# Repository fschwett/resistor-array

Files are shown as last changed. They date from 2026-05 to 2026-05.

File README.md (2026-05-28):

# Resistor array

## Idea:

I wanted to have a resistor array for test purposes. After seeing extremely expensive ones online I decided to create my own. My plan was to order it along with other PCBs, but that didn't end up happening.

## Concept:

An array of resistors which can be added to or removed from the total resistance. I wanted to order five PCBs to be able to play around with values more freely and be able to for example coordinate two resistances. I went with the classic 1, 2, 3, 4 design most of these arrays use. This means I have 1 Ω, 10 Ω, 100 Ω, 1 kΩ, 10 kΩ, 100 kΩ and 1 MΩ, then 2 Ω, 20 Ω and so on. This let's me get any nominal value from 0 Ω to 11.111.110 Ω.

## Implementation:

I had some SMD SPDT slide switches laying around. I chose SMD, because it would give the PCB a clean back. THT could've made contact with other parts and could've ended up shorting the whole thing. For some of the values I had to comine resistors, because I didn't have the right ones or they simple weren't part of the e series. I also used SMD resistors. This had the disadvantage of a low power rating though. Mine are .25 W 1% resistors. Unfortunately I don't know the temperature coefficient of these resistors, but I assume it's between 100 ppm and 200 ppm.

That's the actual design:



The traces are as large as possible to reduce resistance.

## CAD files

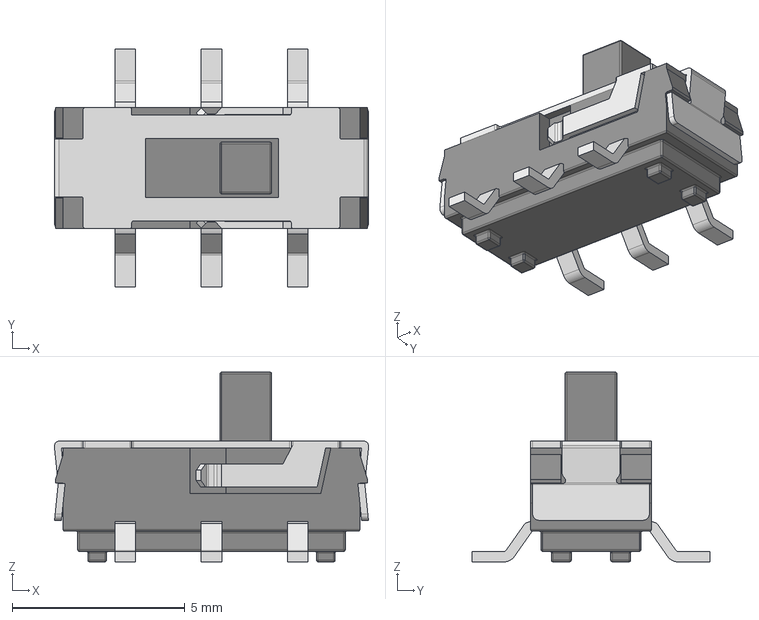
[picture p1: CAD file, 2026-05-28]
KiCad/components/smd-spdt/SLW-913535-2A-SMT.stp
9.10 x 6.90 x 5.50 mm

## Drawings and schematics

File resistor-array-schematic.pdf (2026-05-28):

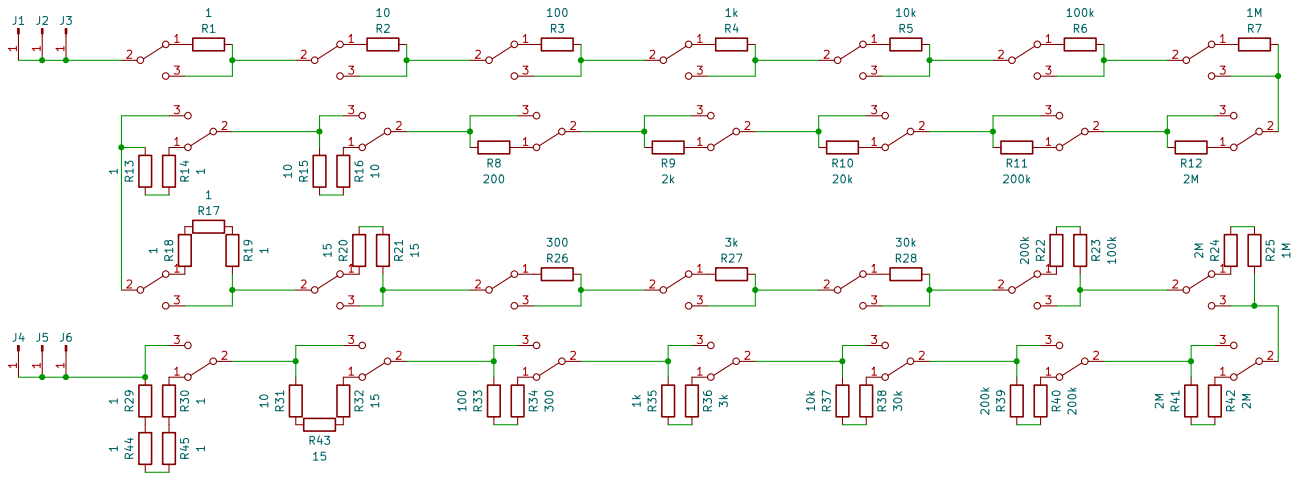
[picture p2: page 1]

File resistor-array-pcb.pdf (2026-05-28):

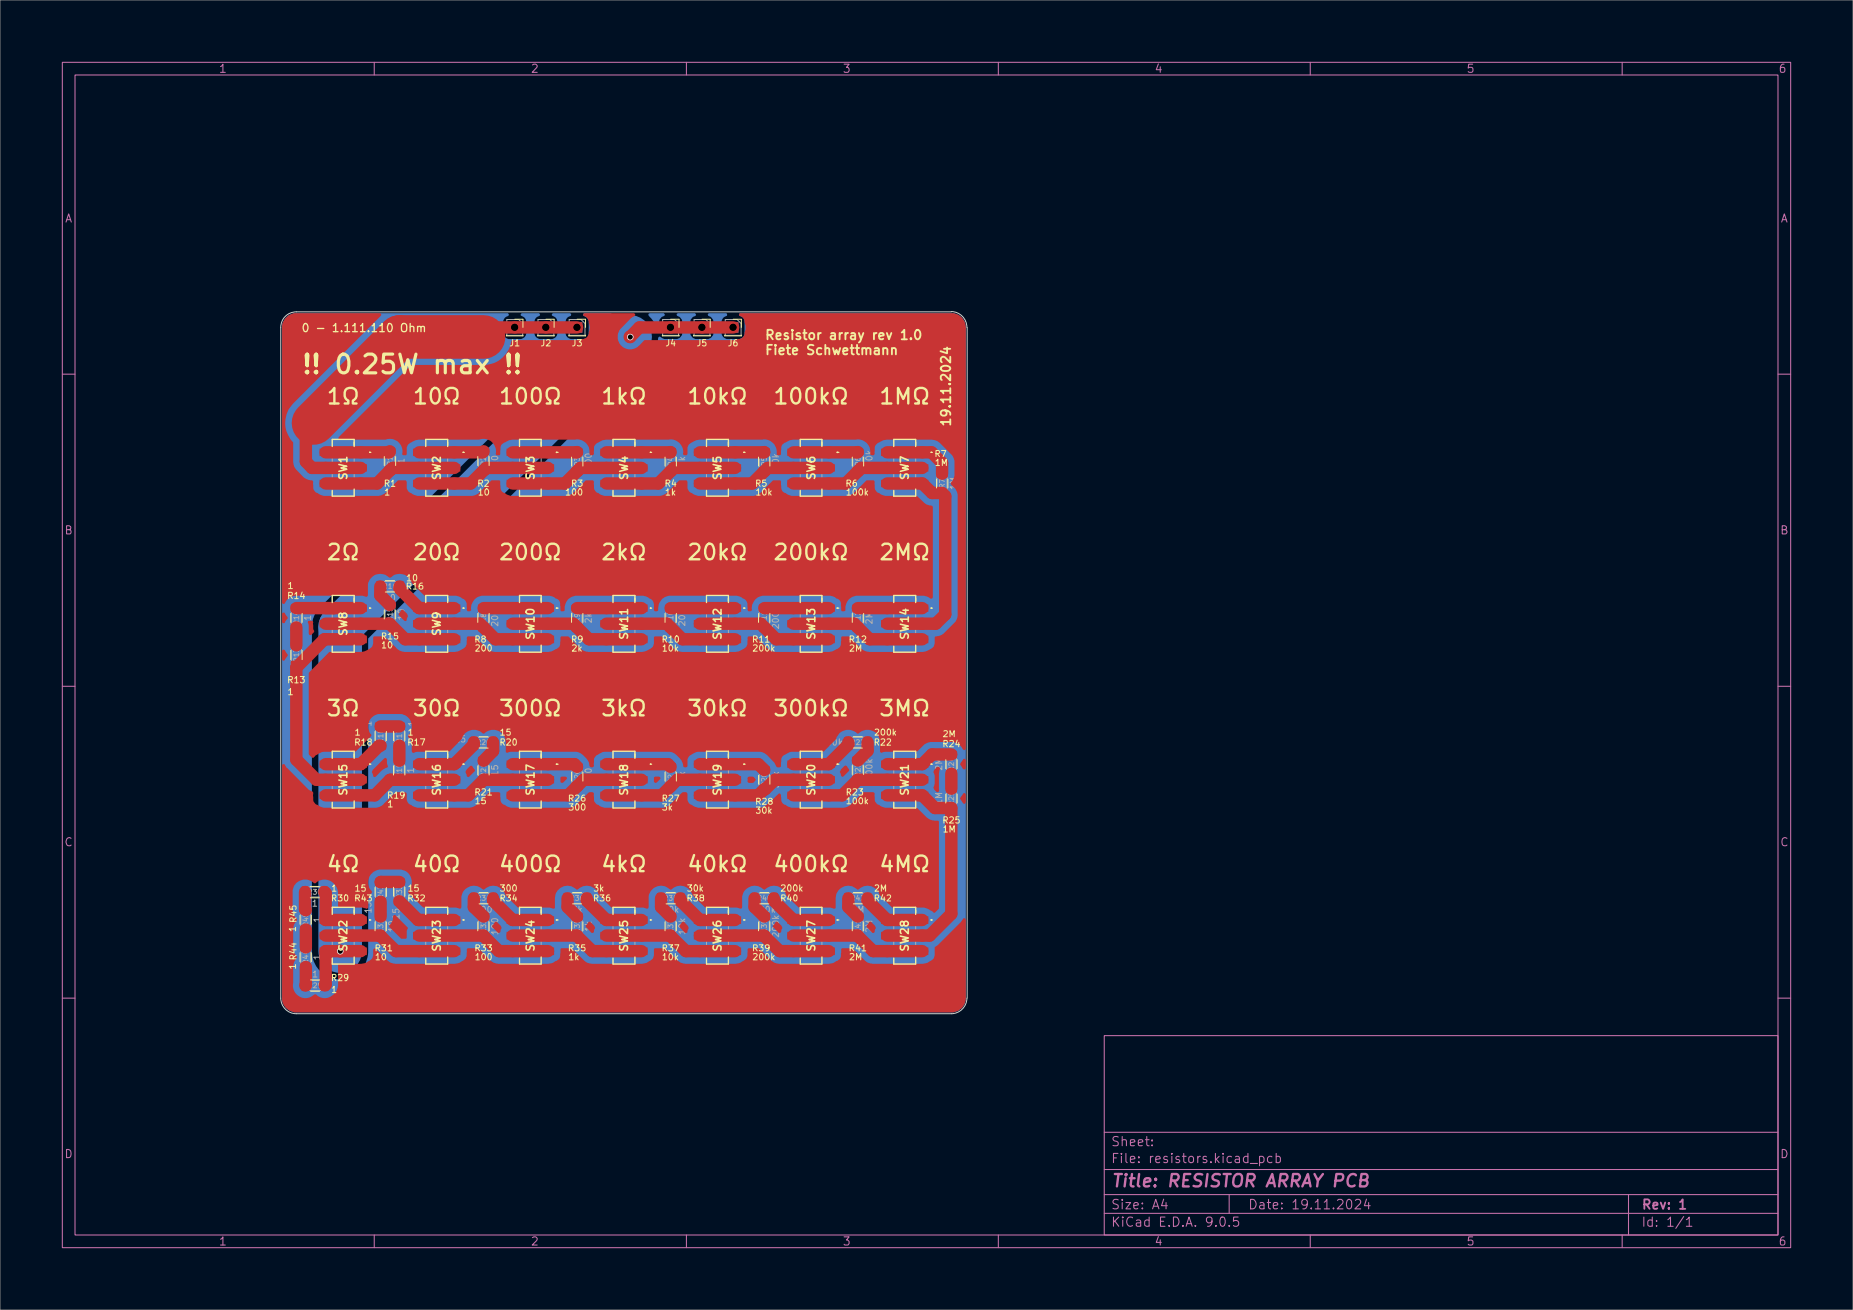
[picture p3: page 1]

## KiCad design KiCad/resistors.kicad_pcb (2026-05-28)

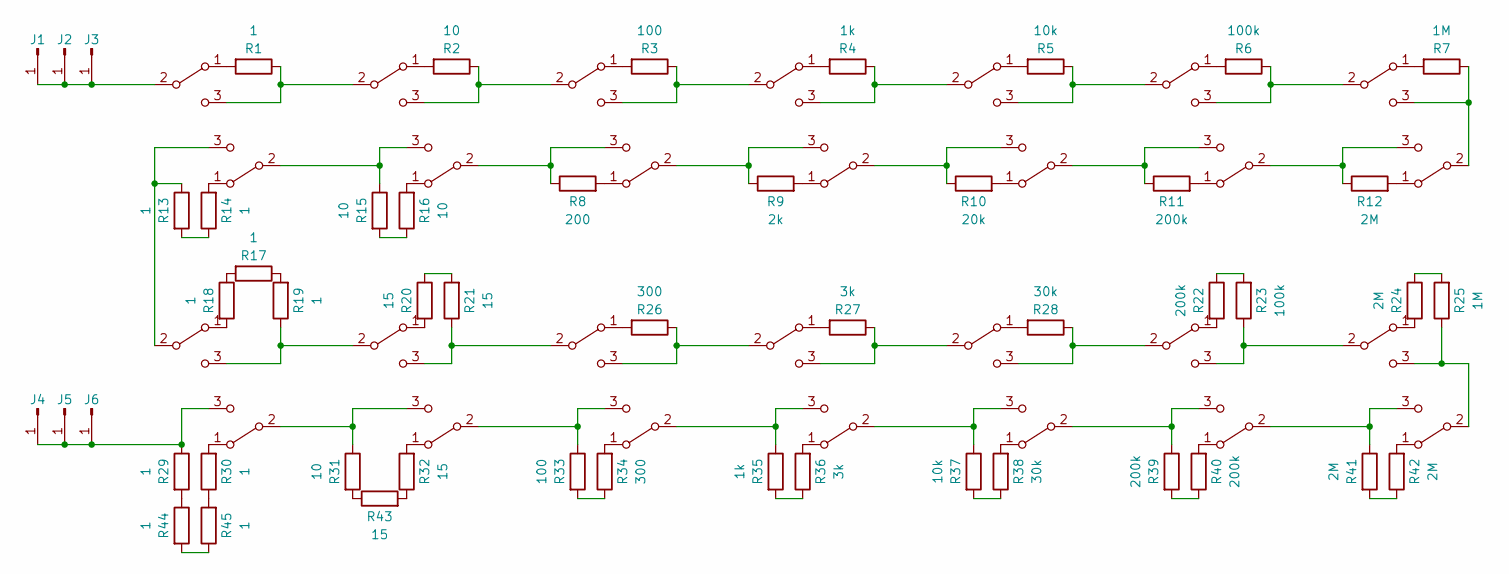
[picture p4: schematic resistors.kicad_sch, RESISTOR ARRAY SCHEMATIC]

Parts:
J1, J2, J3, J4, J5, J6: Conn_01x01_Pin; PinSocket_1x01_P2.54mm_Vertical
R1, R13, R14, R17, R18, R19, R29, R30, R44, R45: 1; R_1206_3216Metric_Pad1.30x1.75mm_HandSolder
R2, R15, R16, R31: 10; R_1206_3216Metric_Pad1.30x1.75mm_HandSolder
R3, R33: 100; R_1206_3216Metric_Pad1.30x1.75mm_HandSolder
R4, R35: 1k; R_1206_3216Metric_Pad1.30x1.75mm_HandSolder
R5, R37: 10k; R_1206_3216Metric_Pad1.30x1.75mm_HandSolder
R6, R23: 100k; R_1206_3216Metric_Pad1.30x1.75mm_HandSolder
R7, R25: 1M; R_1206_3216Metric_Pad1.30x1.75mm_HandSolder
R8: 200; R_1206_3216Metric_Pad1.30x1.75mm_HandSolder
R9: 2k; R_1206_3216Metric_Pad1.30x1.75mm_HandSolder
R10: 20k; R_1206_3216Metric_Pad1.30x1.75mm_HandSolder
R11, R22, R39, R40: 200k; R_1206_3216Metric_Pad1.30x1.75mm_HandSolder
R12, R24, R41, R42: 2M; R_1206_3216Metric_Pad1.30x1.75mm_HandSolder
R20, R21, R32, R43: 15; R_1206_3216Metric_Pad1.30x1.75mm_HandSolder
R26, R34: 300; R_1206_3216Metric_Pad1.30x1.75mm_HandSolder
R27, R36: 3k; R_1206_3216Metric_Pad1.30x1.75mm_HandSolder
R28, R38: 30k; R_1206_3216Metric_Pad1.30x1.75mm_HandSolder
SW1, SW2, SW3, SW4, SW5, SW6, SW7, SW8, SW9, SW10, SW11, SW12, SW13, SW14, SW15, SW16, SW17, SW18, SW19, SW20, SW21, SW22, SW23, SW24, SW25, SW26, SW27, SW28: SW_SPDT; SLW9135352ASMT

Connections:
unnamed: J1.1, J2.1, J3.1, SW1.2 (B)
unnamed: J4.1, J5.1, J6.1, R29.1, SW22.3 (C)
unnamed: R13.2, R14.1
unnamed: R15.2, R16.1
unnamed: R17.1, R19.2
unnamed: R17.2, R18.1
unnamed: R20.1, R21.2
unnamed: R22.1, R23.2
unnamed: R24.1, R25.2
unnamed: R29.2, R44.1
unnamed: R30.1, R45.2
unnamed: R31.2, R43.1
unnamed: R32.1, R43.2
unnamed: R33.2, R34.1
unnamed: R35.2, R36.1
unnamed: R37.2, R38.1
unnamed: R39.2, R40.1
unnamed: R41.2, R42.1
unnamed: R44.2, R45.1
unnamed: R1.2, SW1.1 (A)
unnamed: R1.1, SW1.3 (C), SW2.2 (B)
unnamed: R2.2, SW2.1 (A)
unnamed: R2.1, SW2.3 (C), SW3.2 (B)
unnamed: R3.2, SW3.1 (A)
unnamed: R3.1, SW3.3 (C), SW4.2 (B)
unnamed: R4.2, SW4.1 (A)
unnamed: R4.1, SW4.3 (C), SW5.2 (B)
unnamed: R5.2, SW5.1 (A)
unnamed: R5.1, SW5.3 (C), SW6.2 (B)
unnamed: R6.2, SW6.1 (A)
unnamed: R6.1, SW6.3 (C), SW7.2 (B)
unnamed: R7.2, SW7.1 (A)
unnamed: R14.2, SW8.1 (A)
unnamed: R15.1, SW8.2 (B), SW9.3 (C)
unnamed: R16.2, SW9.1 (A)
unnamed: R8.2, SW10.1 (A)
unnamed: R9.1, SW10.2 (B), SW11.3 (C)
unnamed: R8.1, SW9.2 (B), SW10.3 (C)
unnamed: R9.2, SW11.1 (A)
unnamed: R10.1, SW11.2 (B), SW12.3 (C)
unnamed: R10.2, SW12.1 (A)
unnamed: R11.1, SW12.2 (B), SW13.3 (C)
unnamed: R11.2, SW13.1 (A)
unnamed: R12.1, SW13.2 (B), SW14.3 (C)
unnamed: R12.2, SW14.1 (A)
unnamed: R7.1, SW7.3 (C), SW14.2 (B)
unnamed: R18.2, SW15.1 (A)
unnamed: R13.1, SW8.3 (C), SW15.2 (B)
unnamed: R19.1, SW15.3 (C), SW16.2 (B)
unnamed: R20.2, SW16.1 (A)
unnamed: R21.1, SW16.3 (C), SW17.2 (B)
unnamed: R26.2, SW17.1 (A)
unnamed: R26.1, SW17.3 (C), SW18.2 (B)
unnamed: R27.2, SW18.1 (A)
unnamed: R27.1, SW18.3 (C), SW19.2 (B)
unnamed: R28.2, SW19.1 (A)
unnamed: R28.1, SW19.3 (C), SW20.2 (B)
unnamed: R22.2, SW20.1 (A)
unnamed: R23.1, SW20.3 (C), SW21.2 (B)
unnamed: R24.2, SW21.1 (A)
unnamed: R25.1, SW21.3 (C), SW28.2 (B)
unnamed: R30.2, SW22.1 (A)
unnamed: R31.1, SW22.2 (B), SW23.3 (C)
unnamed: R32.2, SW23.1 (A)
unnamed: R33.1, SW23.2 (B), SW24.3 (C)
unnamed: R34.2, SW24.1 (A)
unnamed: R35.1, SW24.2 (B), SW25.3 (C)
unnamed: R36.2, SW25.1 (A)
unnamed: R37.1, SW25.2 (B), SW26.3 (C)
unnamed: R38.2, SW26.1 (A)
unnamed: R39.1, SW26.2 (B), SW27.3 (C)
unnamed: R40.2, SW27.1 (A)
unnamed: R41.1, SW27.2 (B), SW28.3 (C)
unnamed: R42.2, SW28.1 (A)

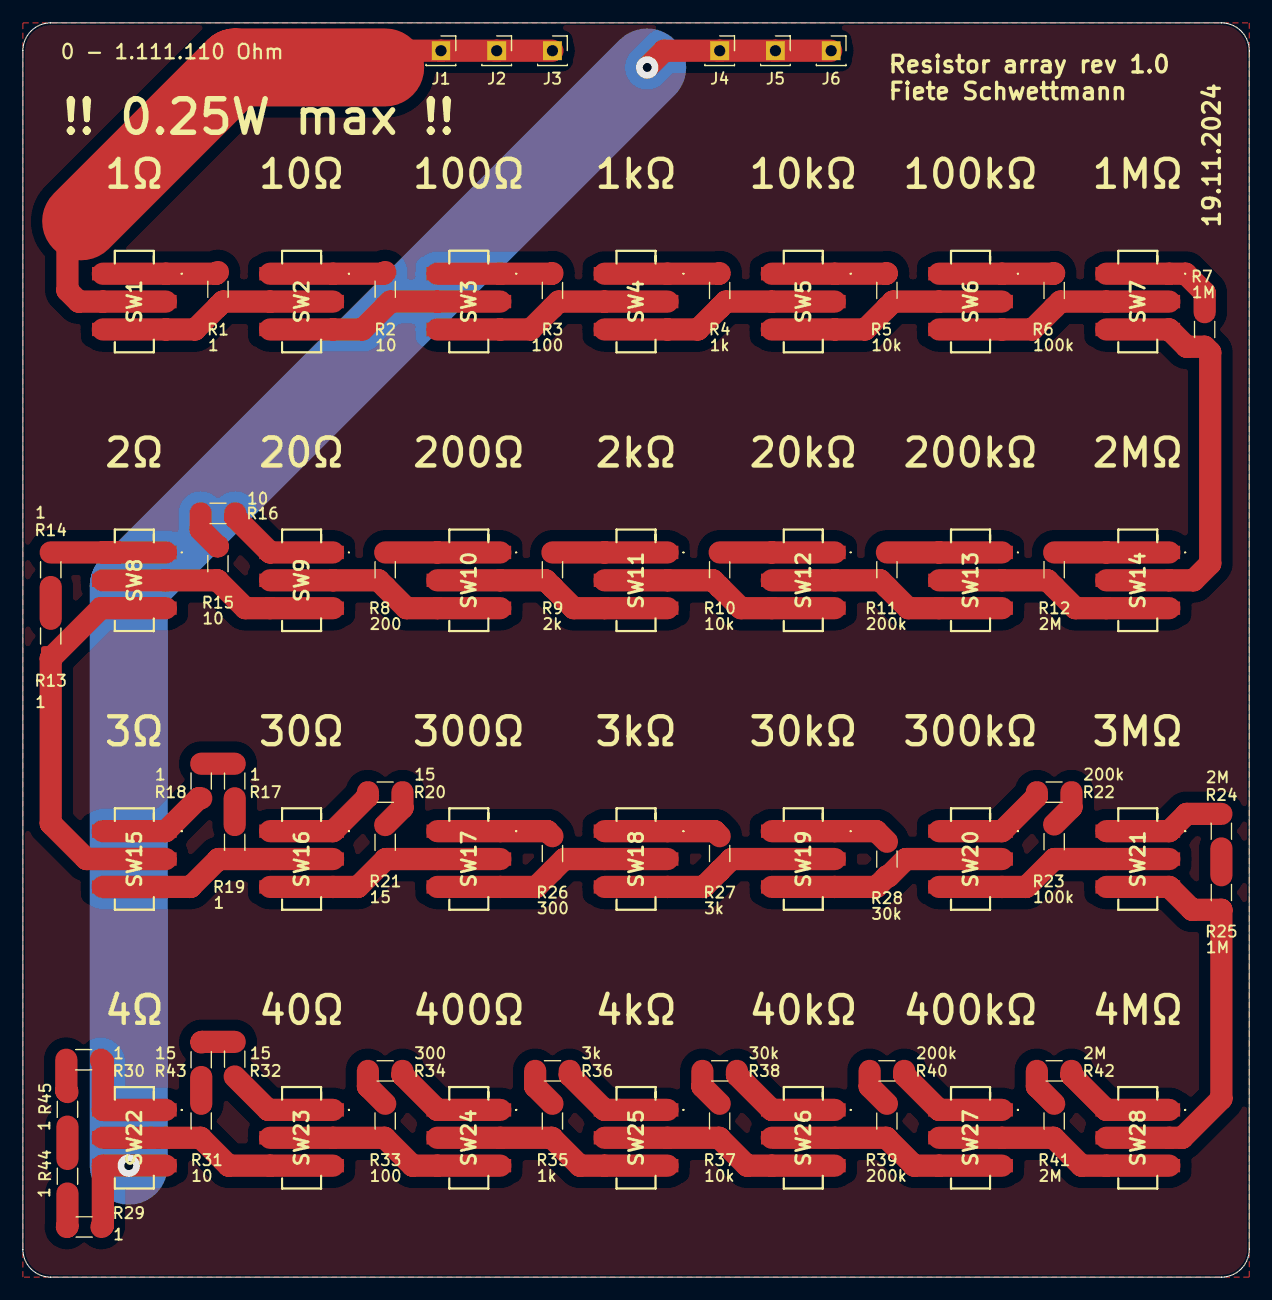
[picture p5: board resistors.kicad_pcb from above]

Board: 2 copper layers, 110.0 x 112.5 mm, 79 parts (0 on the bottom side), 74 nets.
